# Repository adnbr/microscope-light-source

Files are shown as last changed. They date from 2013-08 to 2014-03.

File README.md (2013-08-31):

Microscope Light Source
=======================

A simple PWM capable constant current source for a high brightness LED
based around an ATtiny13 and an LM317 voltage regulator. 

The board has been designed to be primarily one-sided, it should be
possible to etch it DIY. This hasn't been tested though. The top copper
layer only has a ground fill and the extra unused pins brought out to
pads for possible use at a later date. 

You can find out more [here](http://bit.ly/1d51tgB).

Mentioned [here](http://bit.ly/17b90Ci).

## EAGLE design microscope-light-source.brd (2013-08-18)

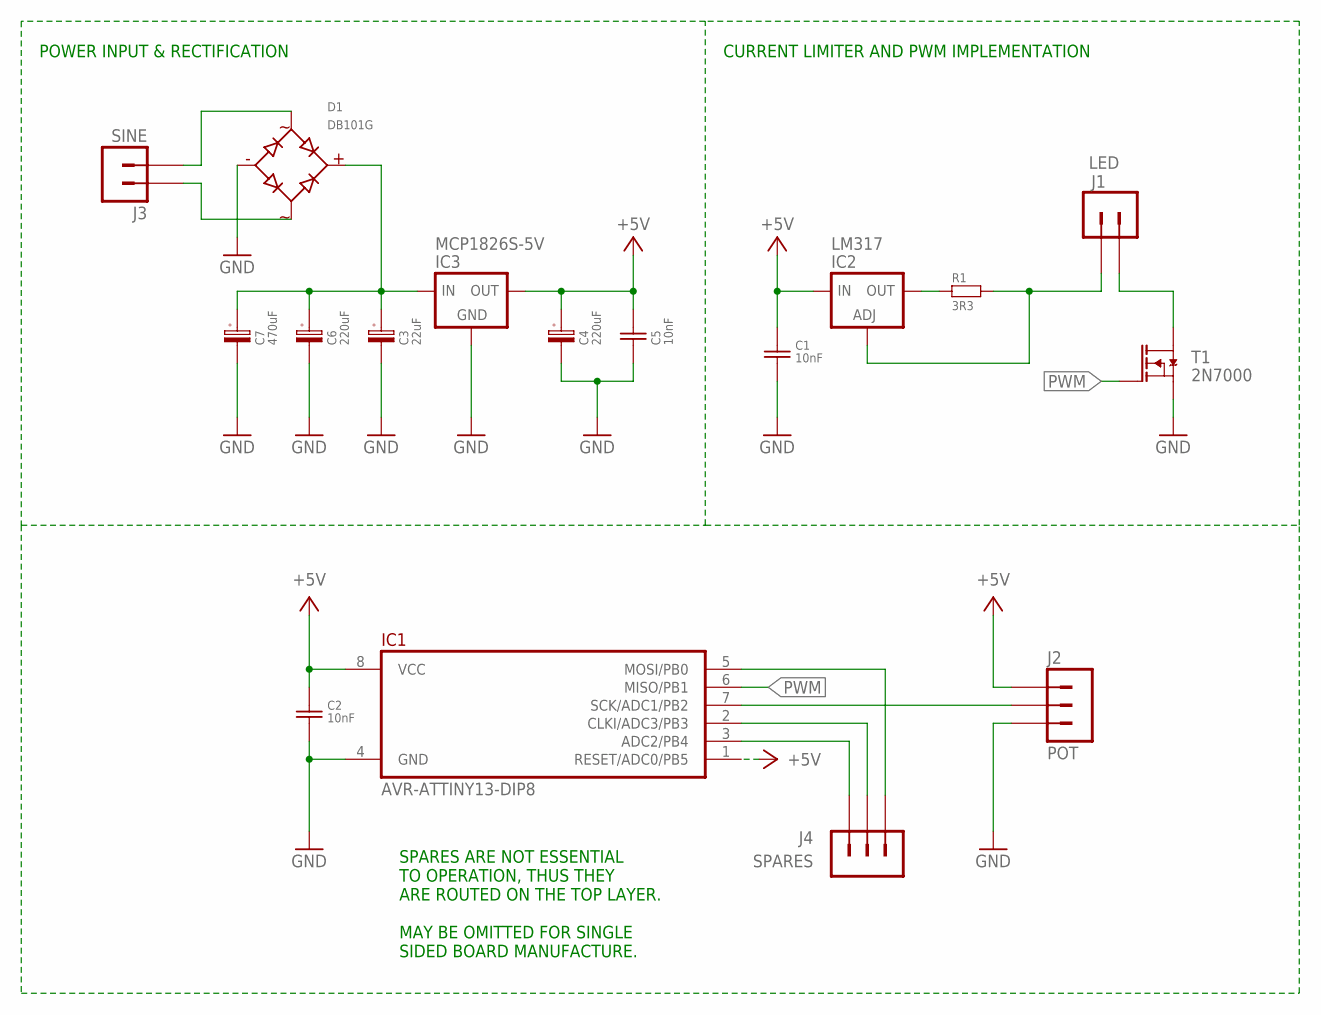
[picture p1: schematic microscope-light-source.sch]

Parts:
C1, C2, C5: 10nF; CAPACITOR-5MM-GRID
C3: 22uF; CAPACITOR-RADIAL-5MM
C4, C6: 220uF; CAPACITOR-RADIAL-5MM
C7: 470uF; CAPACITOR-RADIAL-10MM
D1: DB101G; DIL04-3-BRIDGE-RECTIFIER
IC1: AVR-ATTINY13-DIP8; DIL08-3
IC2: LM317; TO220-HORZ-DRILL
IC3: MCP1826S-5V; TO220-HORZ-DRILL
J1: LED; J02-LONG
J2: POT; J03-LONG
J3: SINE; J02-LONG
J4: SPARES; J03-NOSILK
R1: 3R3; RESISTOR-4MMX10MM/9
T1: 2N7000; TO92-TRIANGLE

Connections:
+5V: C1.1, C2.1, C4.A, C5.1, IC1.1 (RESET/ADC0/PB5), IC1.8 (VCC), IC2.3 (IN), IC3.3 (OUT), J2.1
GND: C1.2, C2.2, C3.C, C4.C, C5.2, C6.C, C7.C, D1.-, IC1.4 (GND), IC3.2 (GND), J2.3, T1.1 (SOURCE)
unnamed: IC2.2 (OUT), R1.2
unnamed: IC2.1 (ADJ), J1.1, R1.1
unnamed: J1.2, T1.3 (DRAIN)
unnamed: IC1.3 (ADC2/PB4), J4.3
unnamed: IC1.7 (SCK/ADC1/PB2), J2.2
unnamed: IC1.2 (CLKI/ADC3/PB3), J4.2
unnamed: C3.A, C6.A, C7.A, D1.+, IC3.1 (IN)
unnamed: D1.SINE0, J3.2
unnamed: D1.SINE1, J3.1
unnamed: IC1.5 (MOSI/PB0), J4.1
PWM: IC1.6 (MISO/PB1), T1.2 (GATE)

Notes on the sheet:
CURRENT LIMITER AND PWM IMPLEMENTATION
POWER INPUT & RECTIFICATION
SPARES ARE NOT ESSENTIAL TO OPERATION, THUS THEY ARE ROUTED ON THE TOP LAYER. MAY BE OMITTED FOR SINGLE SIDED BOARD MANUFACTURE.

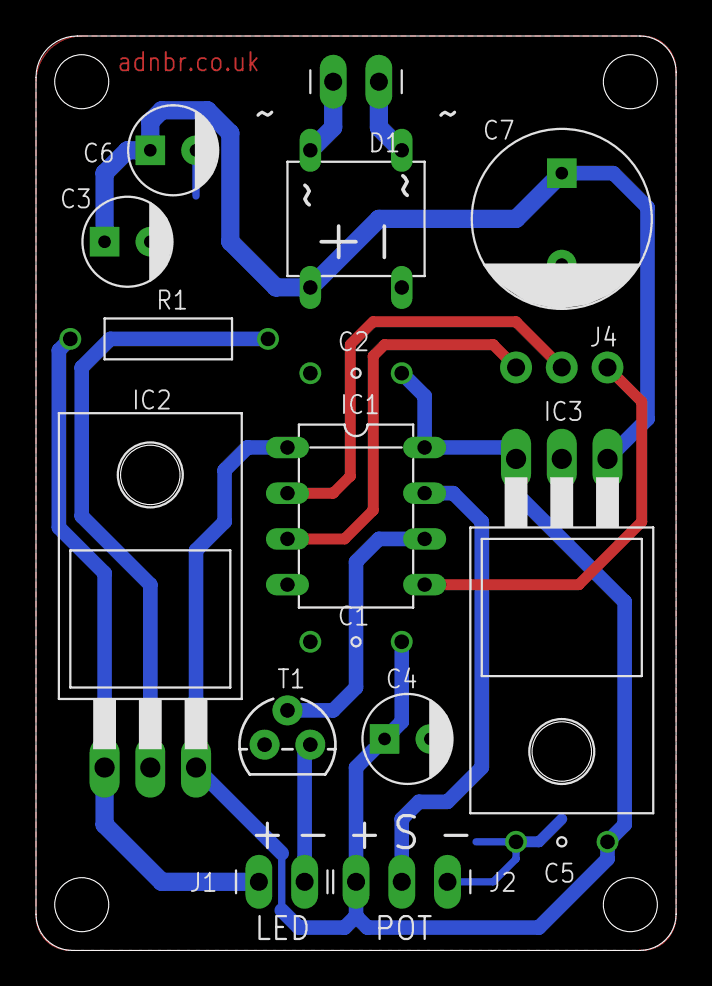
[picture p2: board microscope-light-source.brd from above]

Board: 2 copper layers, 35.6 x 50.8 mm, 17 parts (0 on the bottom side), 13 nets.

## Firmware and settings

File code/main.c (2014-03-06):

/* ---------------------------------------------------------------------
 * PWM LED Brightness control for ATtiny13.
 * Datasheet for ATtiny13: http://www.atmel.com/images/doc2535.pdf
 * 
 * Pin configuration -
 * PB1/OC0B: LED output (Pin 6)
 * PB2/ADC1: Potentiometer input (Pin 7)

 * ~712 bytes.
 * 
 * Find out more: http://bit.ly/1d51tgB
 * -------------------------------------------------------------------*/

// 9.6 MHz, built in resonator
#define F_CPU 9600000
#define LED PB1 

// Point on the scale (0-255) that corresponds to "OFF" on the knob.
#define OFF_BELOW 25

#include <avr/io.h>

// Map from Arduino, see http://arduino.cc/en/reference/map
long map(long x, long in_min, long in_max, long out_min, long out_max)
{
  return (x - in_min) * (out_max - out_min) / (in_max - in_min) + out_min;
}

void adc_setup (void)
{
    // Set the ADC input to PB2/ADC1, left align result
    ADMUX |= (1 << MUX0) | (1 << ADLAR);

    // Set the prescaler to clock/128 & enable ADC
    // At 9.6 MHz this is 75 kHz.
    // See ATtiny13 datasheet, Table 14.4.
    ADCSRA |= (1 << ADPS1) | (1 << ADPS0) | (1 << ADEN);

    // Start the first conversion
    ADCSRA |= (1 << ADSC);
}

int adc_read (void)
{
    // Get the 8-bit result.
    int adc_result = ADCH;

    // Start the next conversion
    ADCSRA |= (1 << ADSC);

    return adc_result;
}

void pwm_setup (void)
{
    // Set Timer 0 prescaler to clock/8.
    // At 9.6 MHz this is 1.2 MHz.
    // See ATtiny13 datasheet, Table 11.9.
    TCCR0B |= (1 << CS01);

    // Set to 'Fast PWM' mode
    TCCR0A |= (1 << WGM01) | (1 << WGM00);

    // Clear OC0B output on compare match, upwards counting.
    TCCR0A |= (1 << COM0B0) | (1 << COM0B1);
}

void pwm_write (int val)
{
    OCR0B = val;
}

int main (void)
{
    int brightness = 0;
    int adc_in = 0;

    adc_setup();
    pwm_setup();

    pwm_write(0);
  
    while (1) {
        // Get the ADC value
        adc_in = adc_read();

        // Smooth the original input to stop jumping around.
        // ADC input is quite noisy, needs calming down.
        brightness = (brightness - (brightness / 4)) + (adc_in / 4);

        if (brightness < OFF_BELOW) {
        	// Turn off LED.
        	DDRB &= ~(1 << LED);
            pwm_write(0);
        } else {
        	// LED is output, set PWM brightness.
        	DDRB |= (1 << LED);  
            pwm_write(map(brightness, OFF_BELOW, 255, 255, 0));
        }
    }
}

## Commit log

2013-08-11 First commit.
    [microscope-light-source.brd, microscope-light-source.sch]
2013-08-18 C values, board re-jig
    Values added for capacitors.
    Voltage regulator rotated 180 deg to simplify trace routing.
    [microscope-light-source.brd, microscope-light-source.sch]
2013-08-31 Readme & Code
    Moved to 10 bit ADC result. Smoother output. 1023 mapped to 255 using
    Arduino map function, see comments for link.
    All data filtered now, some stepping while changing values, not an
    issue. Now more stable in the lower ranges, won't jitter as easily when
    on the bounds of off segment.
    Now phase correct PWM.
    [main.c]
2014-03-01 Rewritten, easier to read, use, etc.
    8-bit ADC directly to PWM. dedicated setup/read/write functions for ADC
    and PWM.
    Clearer comments for bit-wrangling sections of the setup (mentions
    appropriate tables in datasheet for future reference.)
2014-03-06 Catastrophic ADC error, re-map
    Fixed catastrophic problem with ADC - not an issue here, but poor form.
    Also re-introduced mapping (from Arduino library) so the full range of
    brightness is available past "off". ~712 bytes written to flash.
    [main.c]
